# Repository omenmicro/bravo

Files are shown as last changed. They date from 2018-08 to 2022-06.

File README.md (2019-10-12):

# OMEN BRAVO

As-easy-as-possible, but still expandable single board computer with 65C02 CPU.



Become a Patron! (https://www.patreon.com/bePatron?u=23689010)

- [Essential ICs on AliExpress](https://alitronik.com/omen-bravo-pack/)
- [Essential ICs on eBay](https://alitronik.com/omen-bravo-pack-ebay/)

[BOM - Needed parts](./BOM.md)

### Issue 4 is available

Issue 3 adds a 6522 VIA circuit. It features:

- A pair of 8bit parallel ports.
- Each pin of each port can be individually set to the input or to the output.
- Serializer (8 bit shift register)
- A pair of 16bit timer / counter

Issue 4 fixes some problems in the Issue 3 design. See below.

### Issue 3 problem fix

Issue 3 board has some design problems, which is fixed in the Issue 4. Issue 3 is fully working, but you have to manual solder:

- A wire between GND port and a pin 8 of the 74HC138.
- A 180k resistor parallel to the Q1 (between the CPU pins 3 and 37).
- A 47pF capacitor between the CPU pins 1 and 3

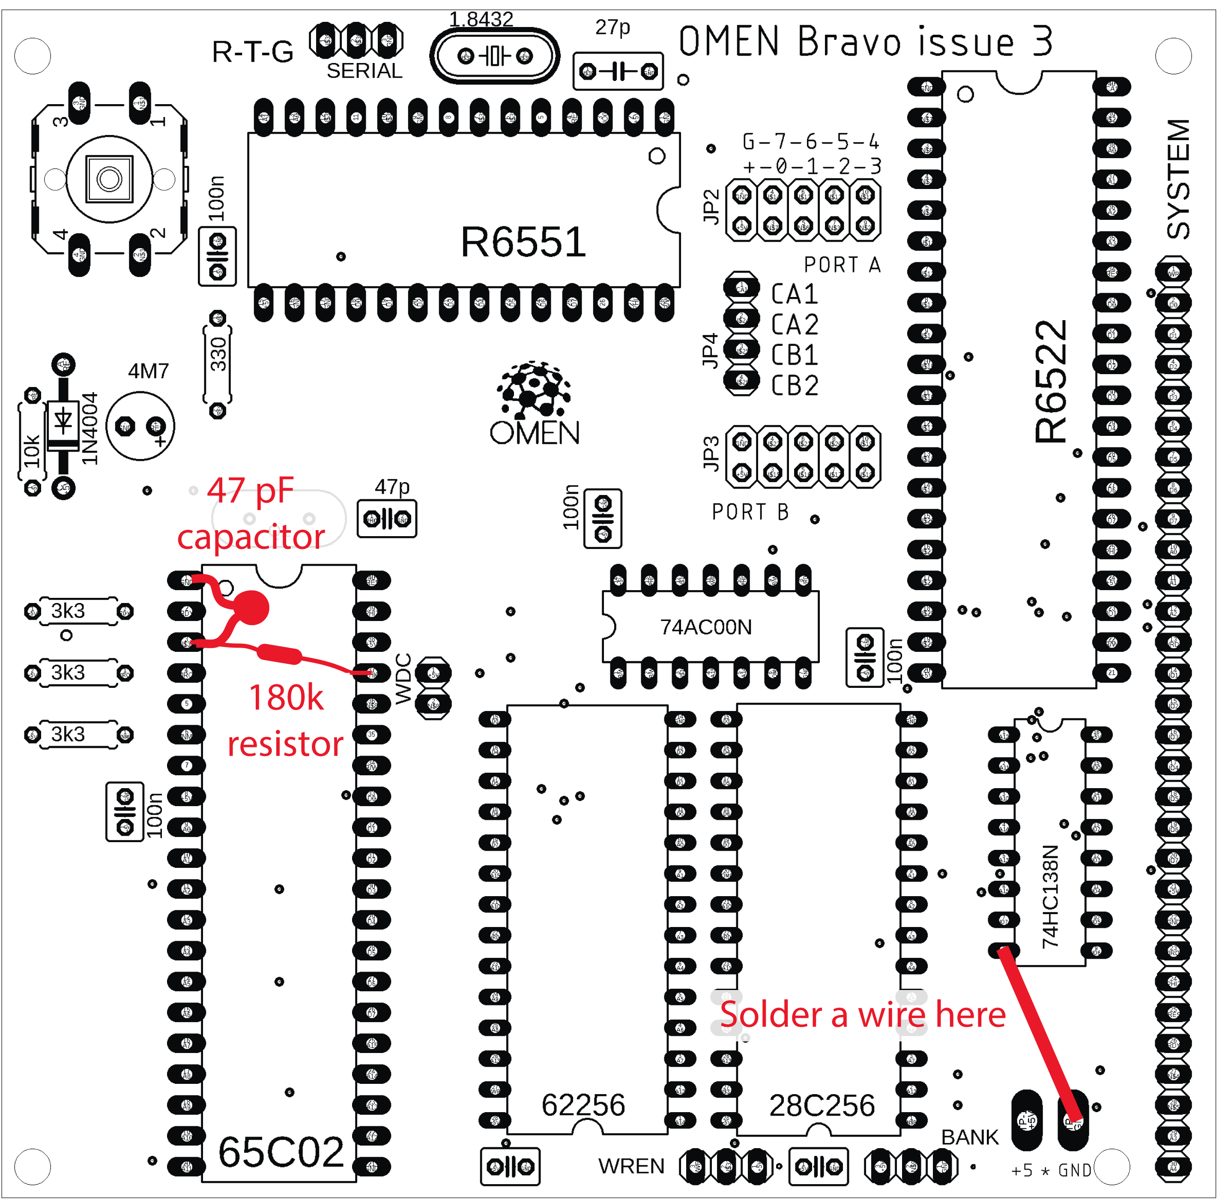
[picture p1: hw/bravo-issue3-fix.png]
Issue 3 fixes


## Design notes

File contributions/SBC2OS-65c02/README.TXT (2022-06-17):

https://sbc.rictor.org/sbcos.html

Here are my SBC-2 Operating System Source Files.

They include:

sbc.asm   - The build file that includes all the other files in the proper order
            (you would assemble this file with TASS)

upload.asm - XMODEM/CRC & Intel-Hex File Upload support
acia.asm - 65c51 init and IO support for monitor
sbcos.asm - monitor & minassembler
reset.asm - reset and IRQ initialization

Compiled using TASS using the following command line:
TASS /c /lsbc.lbl sbc.asm sbc.bin sbcos.lst

The basic idea is to place the upload tables, page aligned, first @ $F700; then let 
all of the code follow sequentially until done.   

The compiler list output file from TASS is called:
sbc25.lst

The label file contains all the labels and their addresses and is called:
sbc.lbl

There is 1 compiled file included:
sbc25.rom  -  the raw binary object file

Current object code occupies $F700-$FFFF

To modify for another target platform, just update the ACIA1.ASM file to 
support these functions:

ACIA1_init - called from reset.asm - initialize the serial terminal device

ACIA1_Input - called from sbc2os.asm - wait for character from terminal, return in Acc

ACIA1_Scan - called from  sbc2os.asm - test for character from terminal - 
             no wait - return with Carry clear for no character, set for character
             last character will be in Acc if carry set - no need to call ACIA1_Input

ACIA1_Output - called from sbc2os.asm - send char in Acc to terminal

In sbc2os.asm, line 40-42, are the calls used from the OS to the terminal.

One note, in the upload.asm file, there are two direct writes to the ACIA1 data register (ACIA1dat).
These are located at lines 363 and 369.  This is in the IntelHex section that ROss Archer contributed.
I'm not sure if a "jsr output" can be substituted or not.

ACIA1dat is defined in the ACIA1.asm file.

This version generates the CRC tables used by xmodem and intel-hex downloaders.  it saves 512 bytes of 
ROM by placing the tables in RAM.  Lines 90 & 91 of upload.asm contain the pointers to the tables.  Put 
these in RAM where they will not be overwritten by the code being downloaded.  They should be page 
aligned for optimal use.

The SBC-2OS command syntax is as follows:

Syntax = {} required, [] optional, HHHH hex address, DD hex data

[HHHH][ HHHH]{Return} - Hex dump address(s)(up to 16 if no address entered)
[HHHH]{.HHHH}{Return} - Hex dump range of addresses (16 per line)
[HHHH]{:DD}[ DD]{Return} - Change data bytes
[HHHH]{G}{Return} - Execute a program (use RTS to return to monitor)
{HHHH.HHHH>HHHH{I}{Return} - move range at 2nd HHHH down to 1st to 3rd HHHH
{HHHH.HHHH>HHHH{M}{Return} - Move range at 1st HHHH thru 2nd to 3rd HHHH
[HHHH][ HHHH]{Q}{Return} - Text dump address(s)
[HHHH]{.HHHH}{Q}{Return} - Text dump range of addresses (16 per line)
{R}{Return} - Print register contents from memory locations - used after BRK if needed
{U}{Return} - Upload File (Xmodem/CRC or Intel Hex)
{V}{Return} - Monitor Version

Good luck!

Daryl

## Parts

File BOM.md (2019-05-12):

[OMEN Bravo](README.md) BOM:

- CPU 65C02 (R65C02 or equivalent type)
- RAM 32kx8 (62256 or equivalent)
- EEPROM 8kx8 (AT28C64 or equivalent, programmed or empty - select the proper variant, or NO EEPROM)
- ACIA (R6551 or equivalent)
- VIA 6522
- Decoder 74138 (HC or HCT)
- Gate 7400 (HC or HCT)
- A printed circuit board
- Crystal 3.6864 MHz (CPU)
- Resonant capacitors 22 pF
- Crystal 1.8432 MHz (for serial communiction)
- Push button
- Diode (1N4004 or similar)
- Resistors (1x 10k, 1x 330R, 1x 180K)
- Electrolytic capacitor 10M
- Filter capacitor (8x 100n)

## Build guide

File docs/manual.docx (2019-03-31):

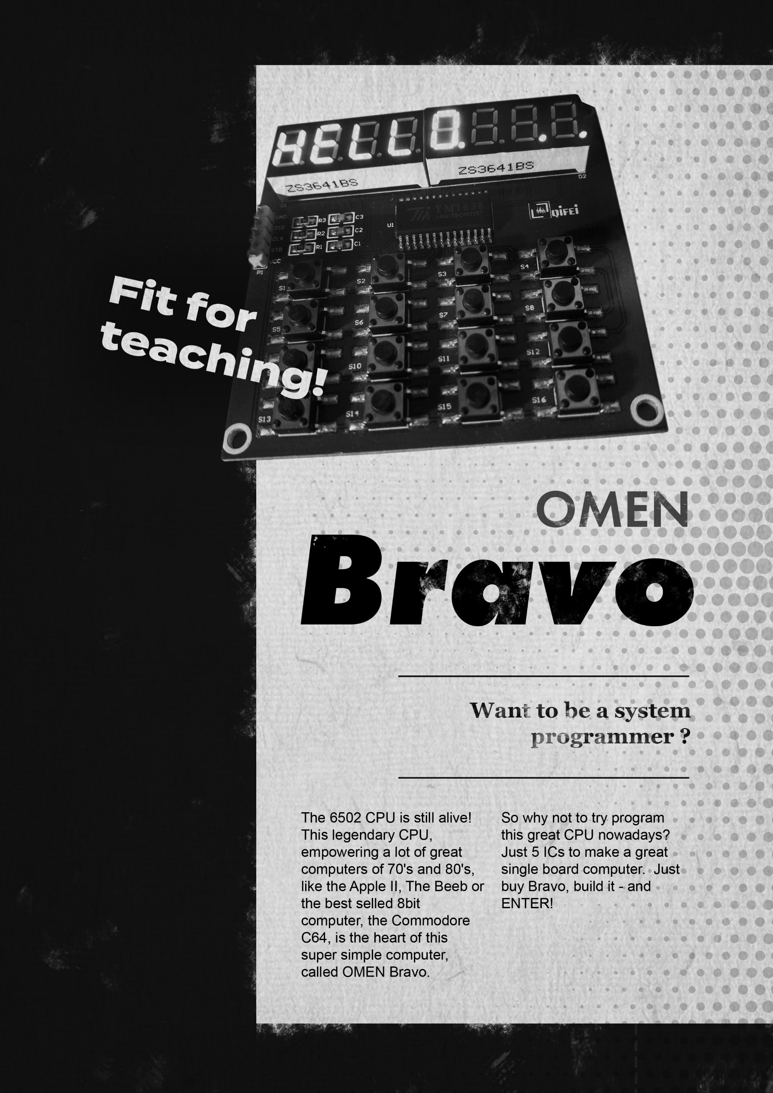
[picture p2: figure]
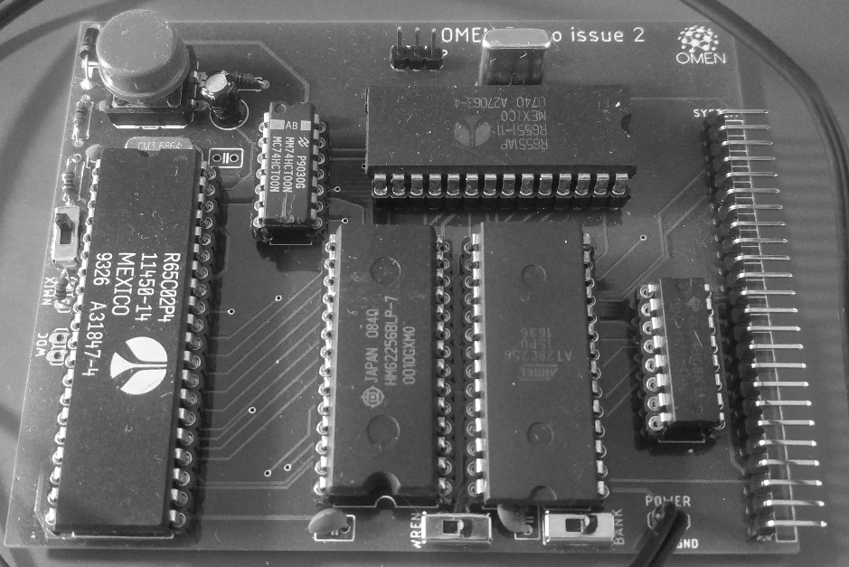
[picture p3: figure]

OMEN Bravo / issue 4

Technical Documentation

INTRODUCTION

===========

The OMEN Bravo computer kit is a low-cost computer trainer, based on the 65C02 CPU. It has these features:

- 65C02 CPU working at 3.6864 MHz
- 32 kB RAM
- 8 kB EEPROM
- Serial port up to 19.200 Bd / MOS 6551 ACIA
- Application system bus

ASSEMBLY INSTRUCTIONS

===================

1. Solder sockets for the integrated circuits
2. Test all soldered connections
  a. Test if all pins are well connected
  b. Check if GND is not short connected to Vcc
  c. Check if each IC has properly connected GND and Vcc
3. Solder all passive parts /capacitors, diode, resistors, push button, crystals/ - pay attention, the Bravo contains two crystals, one for CPU, marked Q1 with value 3.6864, one for serial port, marked “1.8432”
4. Connect the power adapter and check
5. Insert the CPU into its socket /keep the proper orientation!/ and try to power it up. Check if oscillator lives /at CPU pin 39/
6. Insert the essential ICs: 7400, 74138, 62256, 6551 and AT28C64. Again: keep the proper orientation! Bad orientation can damage the IC!
7. Connect the serial pins TxD, RxD and GND /pinhead JP1/ to the TTL-to-USB converter
8. Start the serial terminal on your PC, select proper serial port and set the parameters to 19.200 Bd, 8 data bits, no parity, 1 stop bit.
9. Power your Bravo and check the terminal.

MONITOR

=======

The main software for OMEN Bravo issue 4 is the freeware C’Mon Serial Monitor by Bruce Clark.

You can use the OSI Basic with a minimal effort, as well as the lot of other software.

THE BOARD

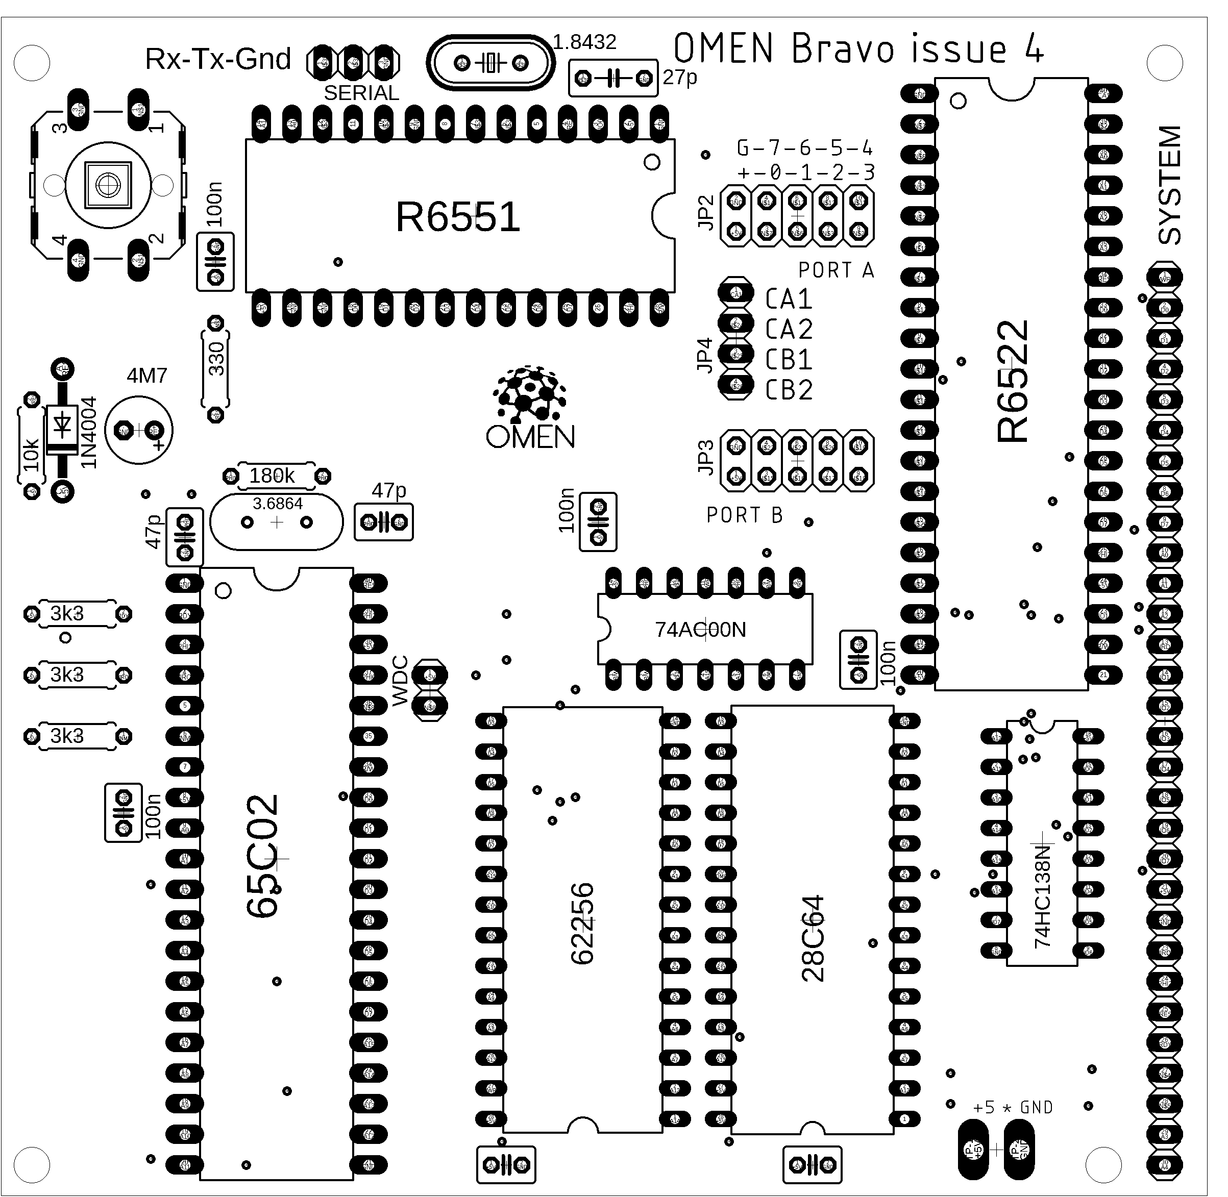
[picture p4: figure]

========

Jumpers and pin headers

SERIAL: Serial port. Pins are RxD, TxD, GND from left to right.

WDC: For Rockwell 65C02 leave open, connect for WDCs W65C02S.

SYSTEM APPLICATION CONNECTOR

=========================

This connector is on the right edge of board. Pin 1 is on the upper side, next to the SYSTEM label.

Pins:

1 /WR
2 D0
3 D1
4 D2
5 D3
6 D4
7 D5
8 D6
9 D7
10 A0
11 A1
12 A2
13 /RD
14 IO1 --- 9000h – 93FFh used for VIA 6522 parallel interface
15 IO2 --- 8800h – 8BFFh
16 IO3 --- 9800h – 9BFFh
17 IO4 --- 8400h – 87FFh IOx signals are decoded by 74138
18 IO5 --- 9400h – 97FFh
19 IO6 --- 8C00h – 8FFFh
20 IO7 --- 9C00h – 9FFFh
21 Vcc
22 GND
23 /IRQ
24 PHI2
25 /RES
26 RDY
27 N/C
28 N/C
29 A3
30 A4

PERIPHERAL IC ADDRESSES
=====================

ACIA 6551:
--------

83FCh – Data Register

83FDh – Status Register

83FEh – Command Register

83FFh - Controll Register

VIA 6522:
-------

93F0h – ORB/IRB
93F1h – ORA/IRA
93F2h – DDRB
93F3h – DDRA
93F4h – T1C-L
93F5h – T1C-H
93F6h – T1L-L
93F7h – T1L-H
93F8h – T2C-L
93F9h – T2C-H
93FAh – SR
93FBh – ACR
93FCh – PCR
93FDh – IFR
93FEh – IER
93FFh – ORA/IRA

MEMORY MAP
==========

0000h – 7FFFh - System RAM 32k

8000h – BFFFh – I/O space, see above

C000h – DFFFh – EEPROM 8k shadow

E000h – FFFFh – EEPROM 8k

C’Mon the Compact Monitor

by Bruce Clark

C'mon, the Compact monitor, is a very small monitor program for the 65C02.

Commands
--------

cr - output a CRLF (and a dash prompt)

0-9A-F - accumulate hex digit

, - store 16-bit "byte" at address, increment address

@ - set address

G - go (call routine)

X - hex/ASCII dump 128 bytes

: - enter the HEX line to store into memory

All other characters are ignored (thus you can use spaces freely). Leading zeros can be omitted. Note that commands execute immediately, i.e. you will get a memory dump when you press X not when you press Enter.

Any routines you call with the G command should return with the D flag clear (they will be called with the D flag clear).

Examples

1234 X - dump 128 bytes starting at address $1234

1234 G - call the routine at address $1234

1234 @ 11,22,33, - store $11, $22 and $33 at address $1234

Single step feature

To single step, use the @ command to set the address, then use the $ (single step) command to single step that instruction. Use $ again to single step the next instruction. After each single step, the program counter (of the next instruction) and the A, S, X, Y, P (in hex), and P (again, but in binary) registers will be output.

If you set the break vector to BREAK, it will save the registers and set the address so that the next instruction (after the signature byte) can be single stepped. Example:

ORG $2000

CLC

LDA #$1234

ADC #$5678

BRK

.byte $0000 ; signature byte (its value is ignored)

EOR #$ABCD

2000G can be used to execute up to the ADC instruction. A subsequent $ command will begin single stepping at the EOR instruction.

Since it isn't always convenient to use BRK, it is also possible to use JSR BRKPT instead of BRK (and its signature byte). Everything about the preceding example would be the same, except that the code would be:

ORG $2000

CLC

LDA #$1234

ADC #$5678

JSR BRKPT

EOR #$ABCD

OMEN Computers - - - https://github.com/osmibity - - - Page: 1

OMEN BRAVO =========

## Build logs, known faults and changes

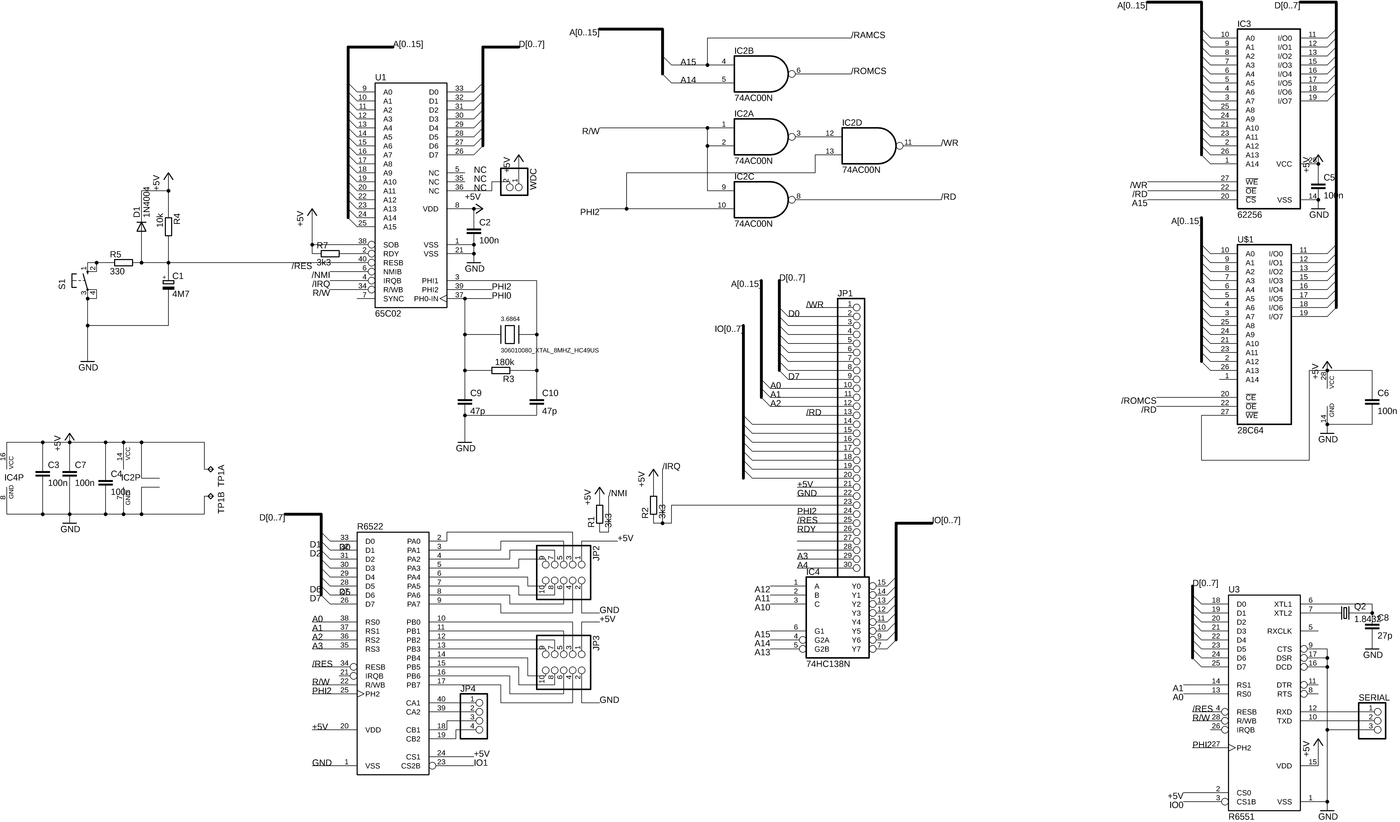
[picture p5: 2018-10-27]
hw/bravo-issue4.png

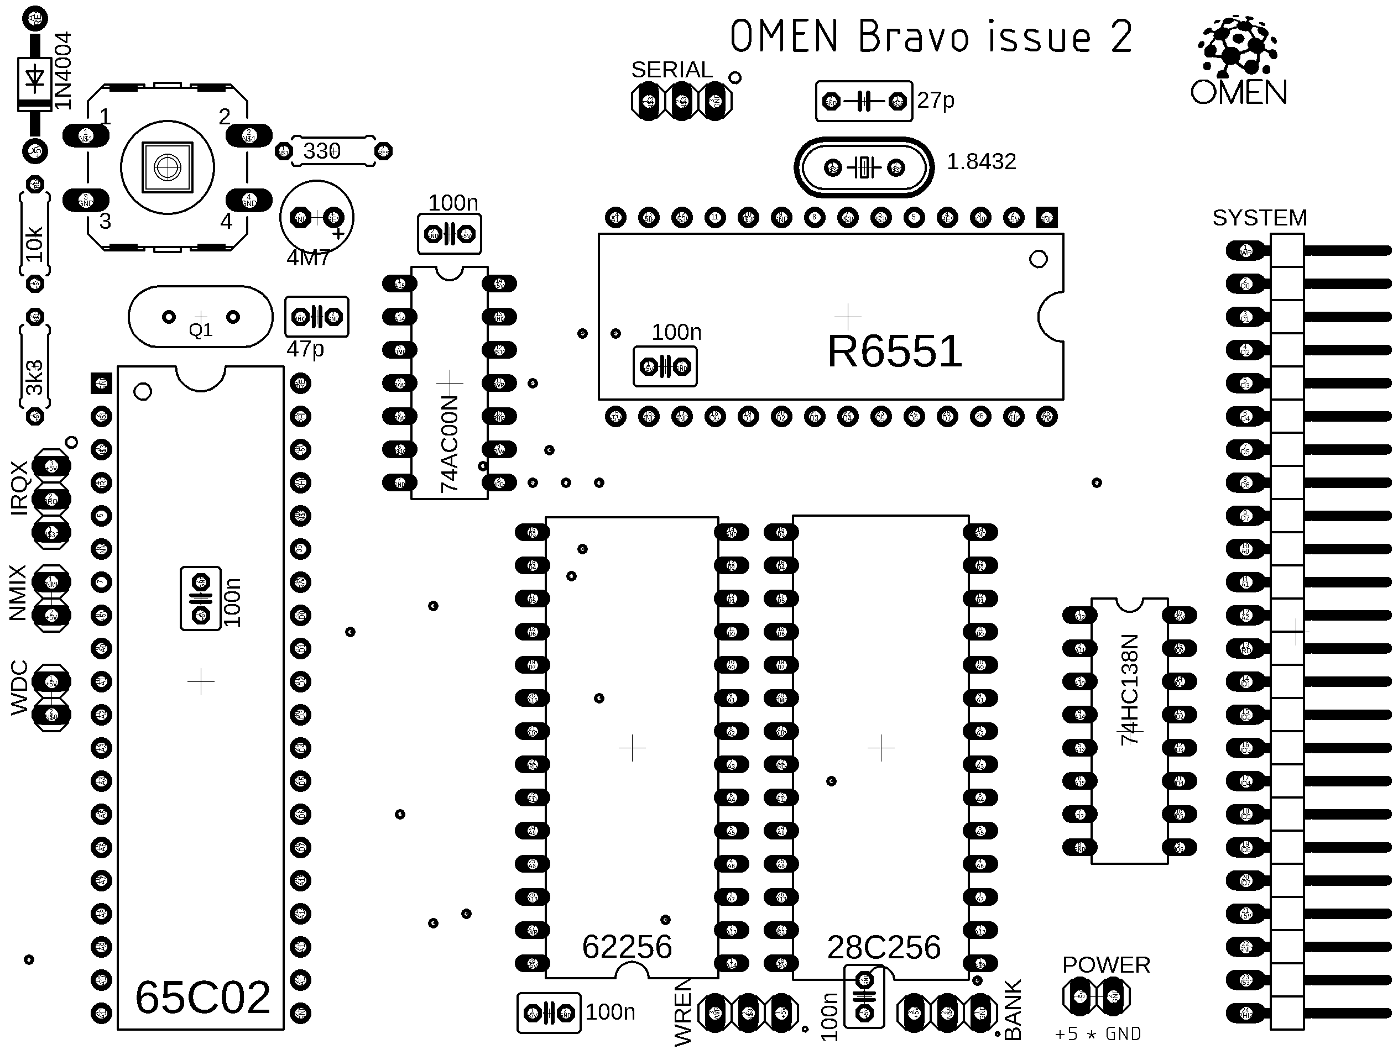
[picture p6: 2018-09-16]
hw/bravo-issue2-board.png

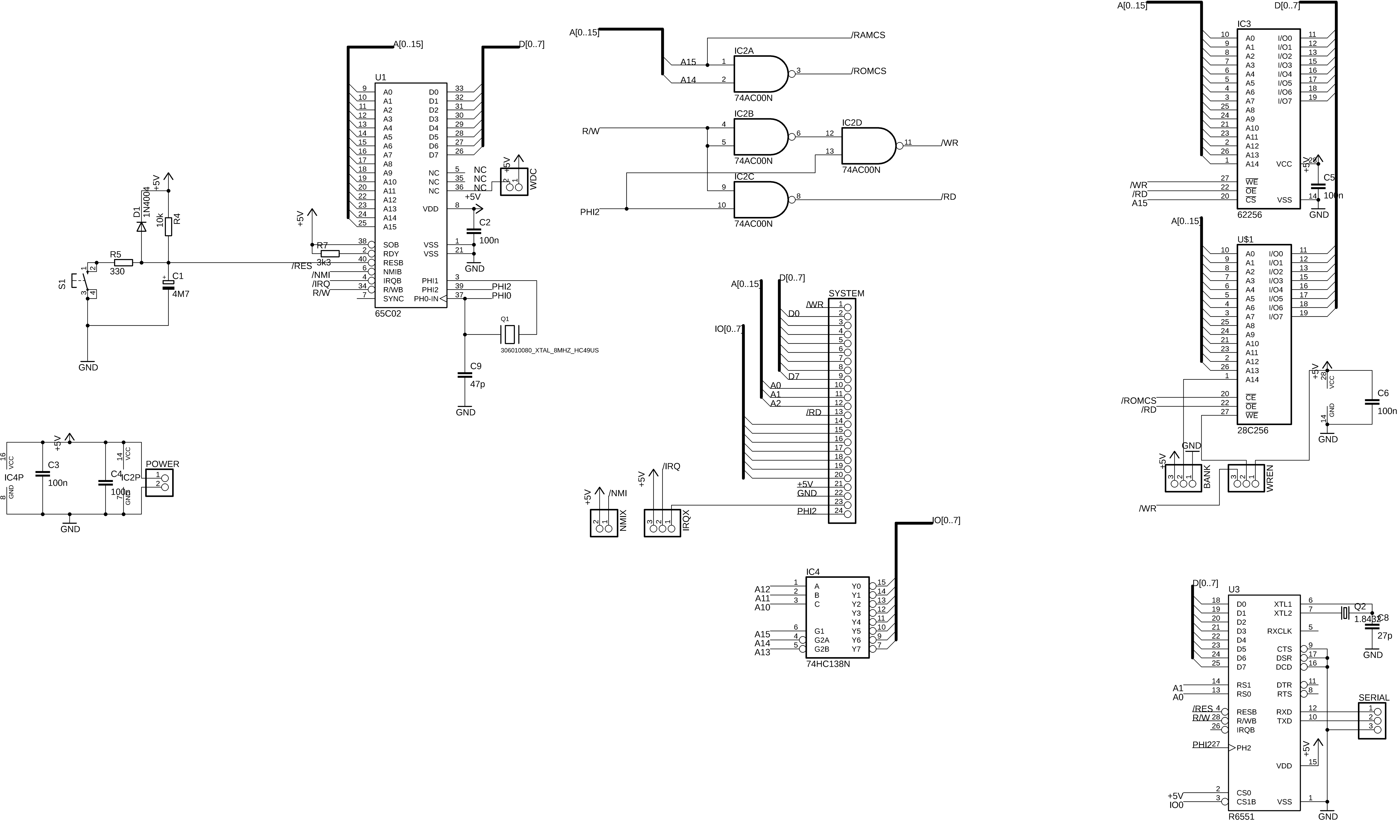
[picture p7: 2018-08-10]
hw/bravo-issue2.png

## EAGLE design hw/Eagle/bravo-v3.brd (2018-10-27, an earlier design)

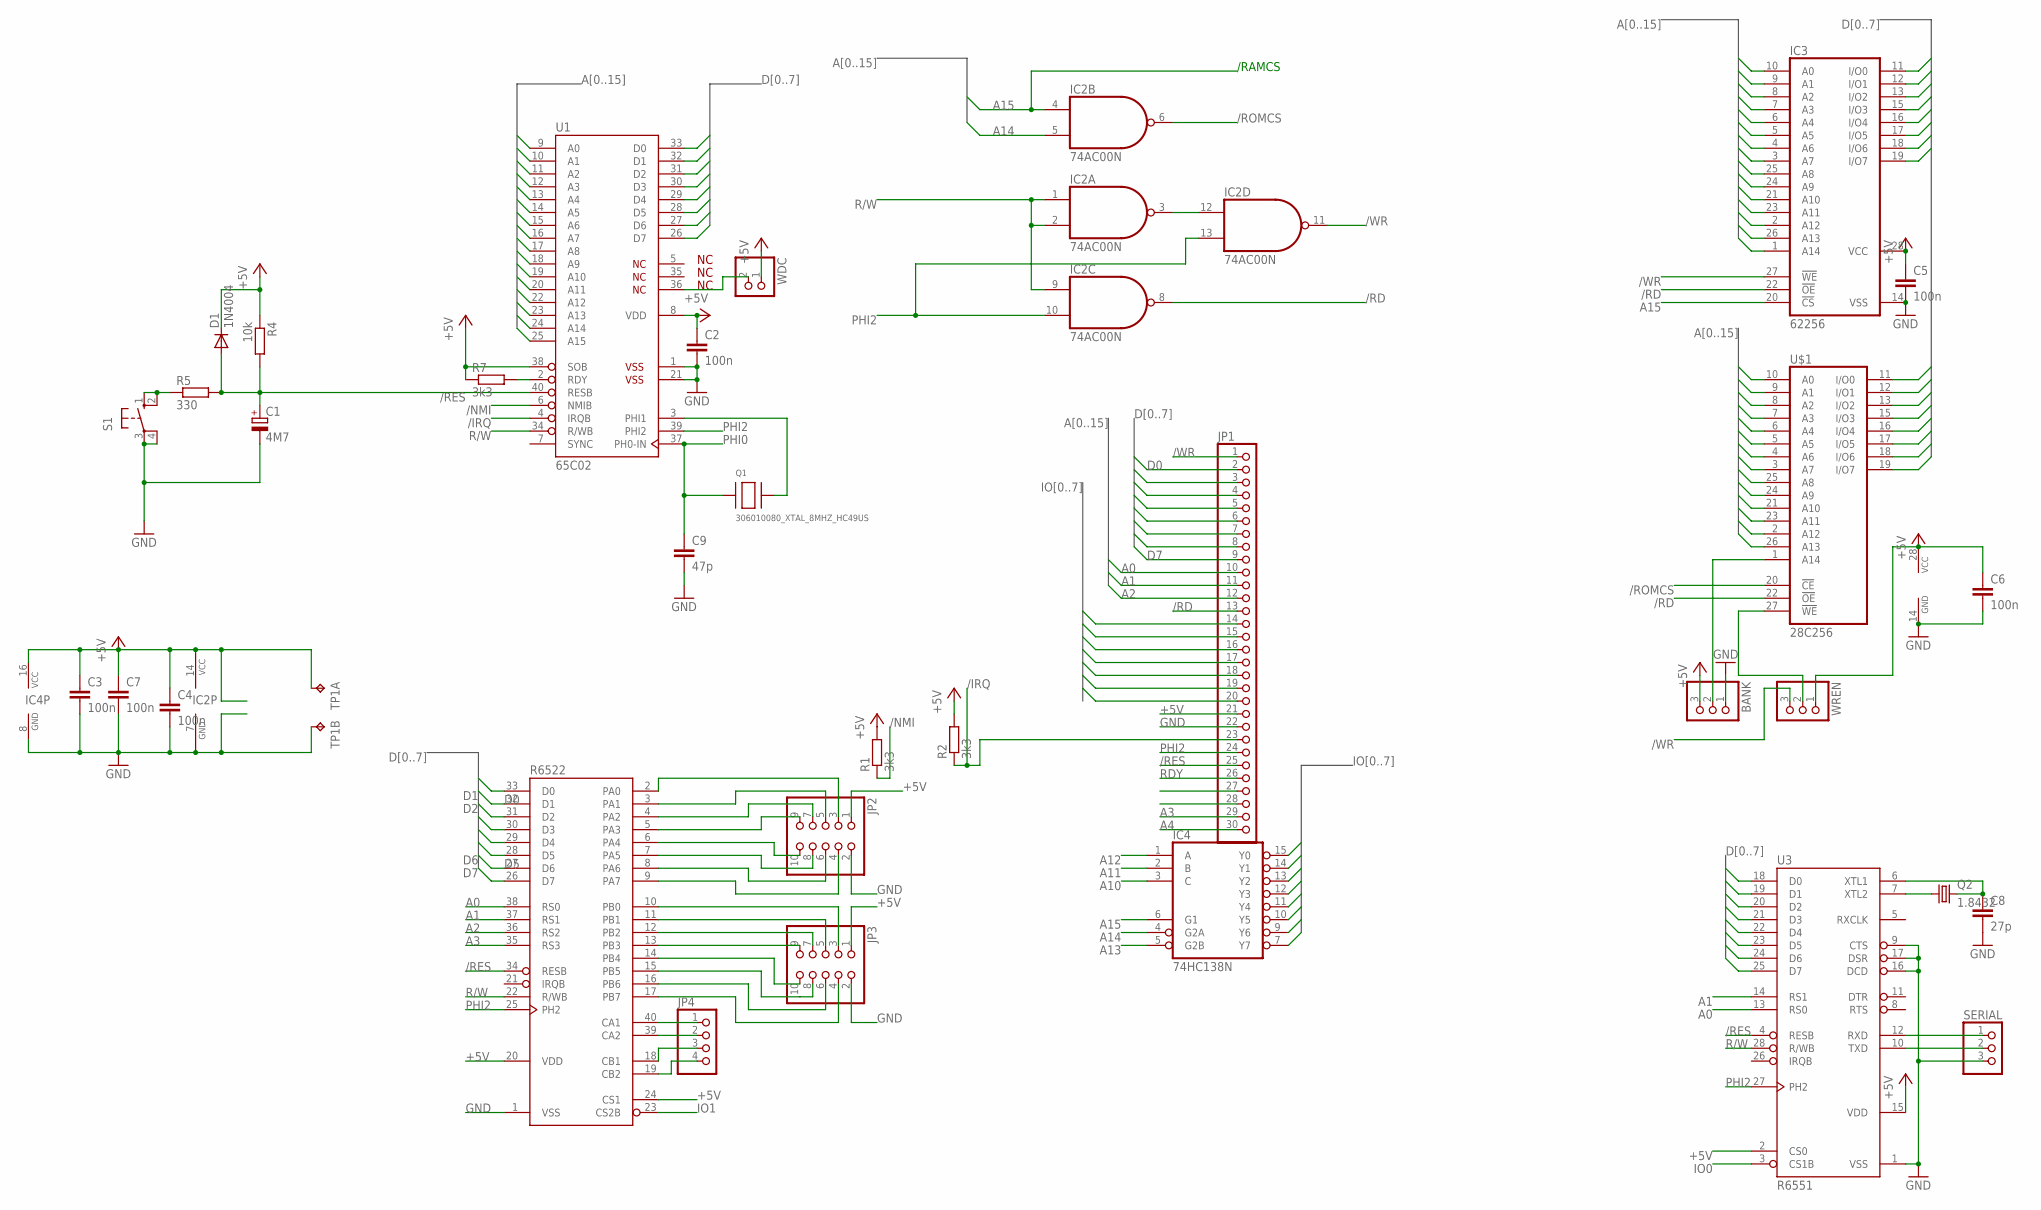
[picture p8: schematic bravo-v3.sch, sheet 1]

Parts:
BANK: PINHD-1X3; 1X03
C1: 4M7; E2,5-6
C2, C3, C4, C5, C6, C7: 100n; C025-030X050
C8: 27p; C050-030X075
C9: 47p; C025-030X050
D1: 1N4004; DO41-10
IC2: 74AC00N; DIL14
IC3: 62256; DIL28-6
IC4: 74HC138N; DIL16
JP1: PINHD-1X30; 1X30
JP2, JP3: PINHD-2X5; 2X05
JP4: PINHD-1X4; 1X04
Q1: 306010080_XTAL_8MHZ_HC49US; HC49US
Q2: 1.8432; HC49/S
R1, R2, R7: 3k3; 0207/7
R4: 10k; 0207/7
R5: 330; 0207/7
R6522: G65SC22P; DIP-40
S1: 40-XX; B3F-40XX
SERIAL: PINHD-1X3; 1X03
TP1: TP2P2-38-17; P2-38-17
U1: 65C02; DIP-40
U3: R6551; DIP-28
U$1: 28C256; DIL28
WDC: PINHD-1X2; 1X02
WREN: PINHD-1X3; 1X03

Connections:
+5V: BANK.3, C2.1, C3.1, C4.1, C5.1, C6.1, C7.1, D1.C, IC2.14 (VCC), IC3.28 (VCC), IC4.16 (VCC), JP1.21, JP2.1, JP3.1, R1.2, R2.2, R4.1, R7.1, R6522.20 (VDD), R6522.24 (CS1), TP1.TP-1, U1.8 (VDD), U1.38 (SOB), U3.2 (CS0), U3.15 (VDD), U$1.28 (VCC), WDC.1, WREN.1
/IRQ: JP1.23, R2.1, U1.4 (IRQB)
/NMI: R1.1, U1.6 (NMIB)
/RD: IC2.8 (O), IC3.22 (!OE), JP1.13, U$1.22 (!OE)
/RES: C1.+, D1.A, JP1.25, R4.2, R5.2, R6522.34 (RESB), U1.40 (RESB), U3.4 (RESB)
/ROMCS: IC2.6 (O), U$1.20 (!CE)
/WR: IC2.11 (O), IC3.27 (!WE), JP1.1, WREN.3
A0: IC3.10 (A0), JP1.10, R6522.38 (RS0), U1.9 (A0), U3.13 (RS0), U$1.10 (A0)
A1: IC3.9 (A1), JP1.11, R6522.37 (RS1), U1.10 (A1), U3.14 (RS1), U$1.9 (A1)
A2: IC3.8 (A2), JP1.12, R6522.36 (RS2), U1.11 (A2), U$1.8 (A2)
A3: IC3.7 (A3), JP1.29, R6522.35 (RS3), U1.12 (A3), U$1.7 (A3)
A4: IC3.6 (A4), JP1.30, U1.13 (A4), U$1.6 (A4)
A5: IC3.5 (A5), U1.14 (A5), U$1.5 (A5)
A6: IC3.4 (A6), U1.15 (A6), U$1.4 (A6)
A7: IC3.3 (A7), U1.16 (A7), U$1.3 (A7)
A8: IC3.25 (A8), U1.17 (A8), U$1.25 (A8)
A9: IC3.24 (A9), U1.18 (A9), U$1.24 (A9)
A10: IC3.21 (A10), IC4.3 (C), U1.19 (A10), U$1.21 (A10)
A11: IC3.23 (A11), IC4.2 (B), U1.20 (A11), U$1.23 (A11)
A12: IC3.2 (A12), IC4.1 (A), U1.22 (A12), U$1.2 (A12)
A13: IC3.26 (A13), IC4.5 (G2B), U1.23 (A13), U$1.26 (A13)
A14: IC2.5 (I1), IC3.1 (A14), IC4.4 (G2A), U1.24 (A14)
A15: IC2.4 (I0), IC3.20 (!CS), IC4.6 (G1), U1.25 (A15)
CA1: JP4.1, R6522.40 (CA1)
D0: IC3.11 (I/O0), JP1.2, R6522.33 (D0), U1.33 (D0), U3.18 (D0), U$1.11 (I/O0)
D1: IC3.12 (I/O1), JP1.3, R6522.32 (D1), U1.32 (D1), U3.19 (D1), U$1.12 (I/O1)
D2: IC3.13 (I/O2), JP1.4, R6522.31 (D2), U1.31 (D2), U3.20 (D2), U$1.13 (I/O2)
D3: IC3.15 (I/O3), JP1.5, R6522.30 (D3), U1.30 (D3), U3.21 (D3), U$1.15 (I/O3)
D4: IC3.16 (I/O4), JP1.6, R6522.29 (D4), U1.29 (D4), U3.22 (D4), U$1.16 (I/O4)
D5: IC3.17 (I/O5), JP1.7, R6522.28 (D5), U1.28 (D5), U3.23 (D5), U$1.17 (I/O5)
D6: IC3.18 (I/O6), JP1.8, R6522.27 (D6), U1.27 (D6), U3.24 (D6), U$1.18 (I/O6)
D7: IC3.19 (I/O7), JP1.9, R6522.26 (D7), U1.26 (D7), U3.25 (D7), U$1.19 (I/O7)
GND: BANK.1, C1.-, C2.2, C3.2, C4.2, C5.2, C6.2, C7.2, C8.2, C9.2, IC2.7 (GND), IC3.14 (VSS), IC4.8 (GND), JP1.22, JP2.2, JP3.2, R6522.1 (VSS), S1.3, S1.4 (P1), SERIAL.3, TP1.TP-2, U1.1 (VSS$1), U1.21 (VSS$2), U3.1 (VSS), U3.9 (CTS), U3.16 (DCD), U3.17 (DSR), U$1.14 (GND)
IO0: IC4.15 (Y0), U3.3 (CS1B)
IO1: IC4.14 (Y1), JP1.14, R6522.23 (CS2B)
IO2: IC4.13 (Y2), JP1.15
IO3: IC4.12 (Y3), JP1.16
IO4: IC4.11 (Y4), JP1.17
IO5: IC4.10 (Y5), JP1.18
IO6: IC4.9 (Y6), JP1.19
IO7: IC4.7 (Y7), JP1.20
unnamed: R5.1, S1.1 (S), S1.2 (S1)
unnamed: JP2.9, R6522.5 (PA3)
unnamed: JP2.7, R6522.4 (PA2)
unnamed: JP2.5, R6522.3 (PA1)
unnamed: JP2.3, R6522.2 (PA0)
unnamed: U1.36 (NC$3), WDC.2
unnamed: BANK.2, U$1.1 (A14)
unnamed: IC2.3 (O), IC2.12 (I0)
unnamed: JP2.10, R6522.6 (PA4)
unnamed: JP2.8, R6522.7 (PA5)
unnamed: JP2.6, R6522.8 (PA6)
unnamed: JP2.4, R6522.9 (PA7)
unnamed: JP3.3, R6522.10 (PB0)
unnamed: JP3.5, R6522.11 (PB1)
unnamed: JP3.7, R6522.12 (PB2)
unnamed: JP3.9, R6522.13 (PB3)
unnamed: JP3.10, R6522.14 (PB4)
unnamed: JP3.8, R6522.15 (PB5)
unnamed: JP3.6, R6522.16 (PB6)
unnamed: JP3.4, R6522.17 (PB7)
unnamed: JP4.2, R6522.39 (CA2)
unnamed: JP4.3, R6522.18 (CB1)
unnamed: JP4.4, R6522.19 (CB2)
unnamed: U$1.27 (!WE), WREN.2
unnamed: Q1.P$2, U1.3 (PHI1)
unnamed: SERIAL.1, U3.12 (RXD)
unnamed: SERIAL.2, U3.10 (TXD)
unnamed: Q2.1, U3.7 (XTL2)
unnamed: C8.1, Q2.2, U3.6 (XTL1)
PHI0: C9.1, Q1.P$1, U1.37 (PH0-IN)
PHI2: IC2.10 (I1), IC2.13 (I1), JP1.24, R6522.25 (PH2), U1.39 (PHI2), U3.27 (PH2)
R/W: IC2.1 (I0), IC2.2 (I1), IC2.9 (I0), R6522.22 (R/WB), U1.34 (R/WB), U3.28 (R/WB)
RDY: JP1.26, R7.2, U1.2 (RDY)

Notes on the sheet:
/RAMCS

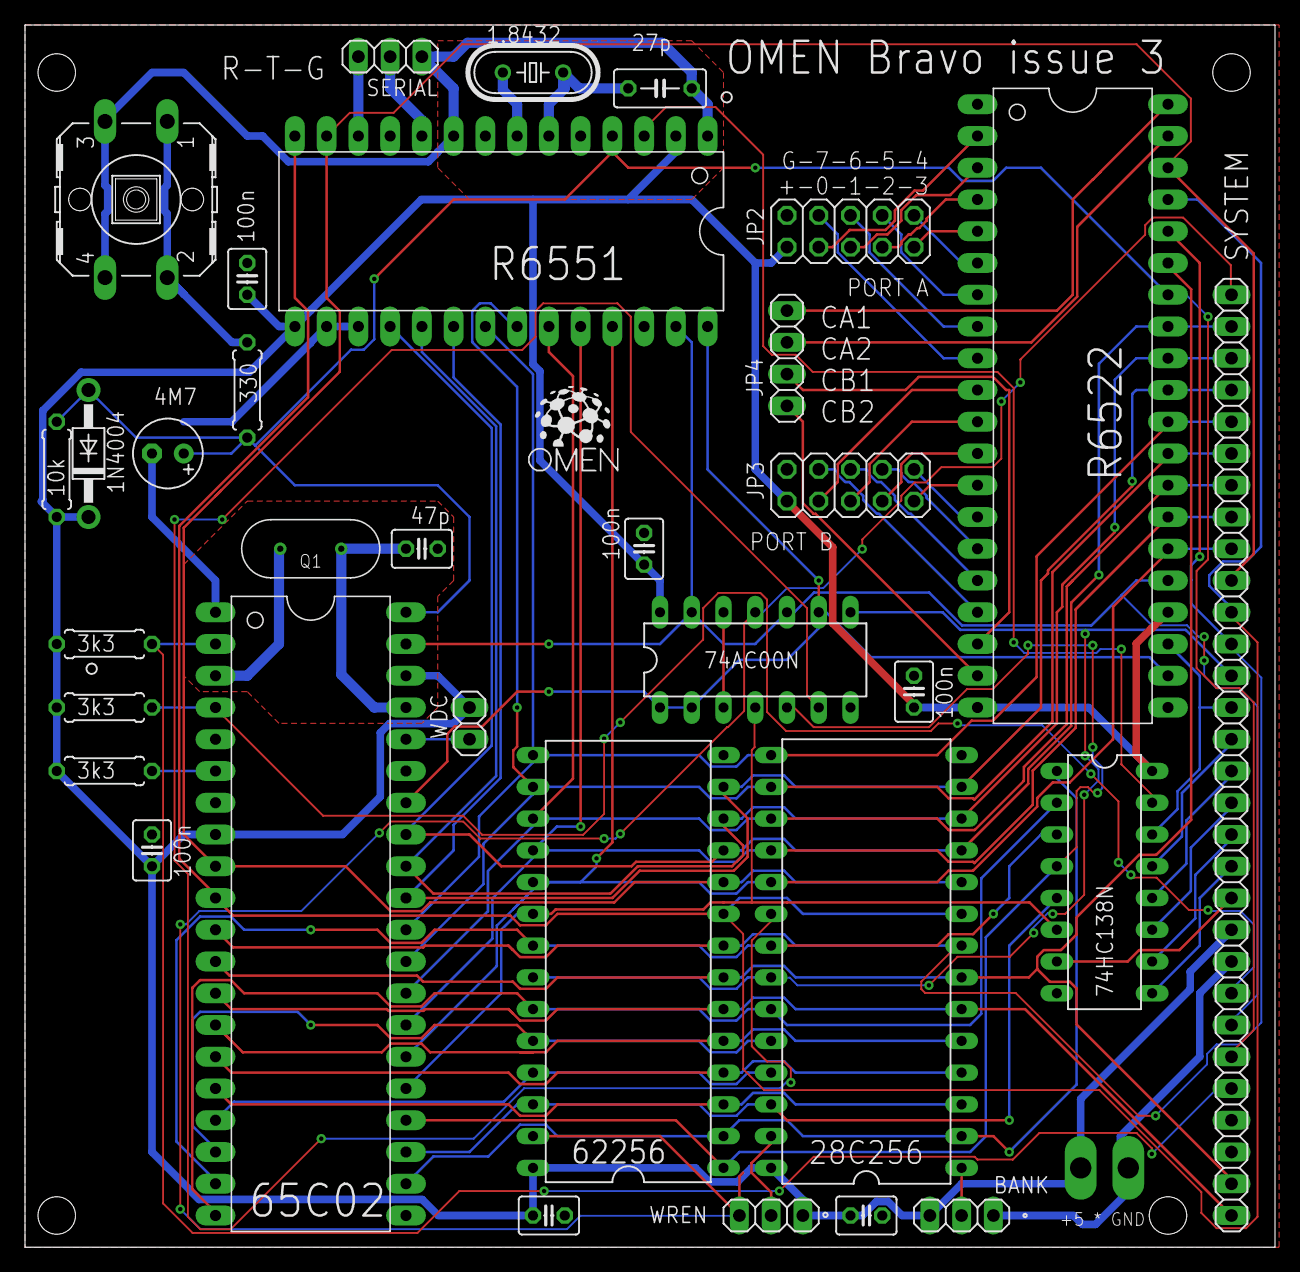
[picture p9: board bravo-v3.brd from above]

Board: 2 copper layers, 100.0 x 97.8 mm, 34 parts (0 on the bottom side), 74 nets.

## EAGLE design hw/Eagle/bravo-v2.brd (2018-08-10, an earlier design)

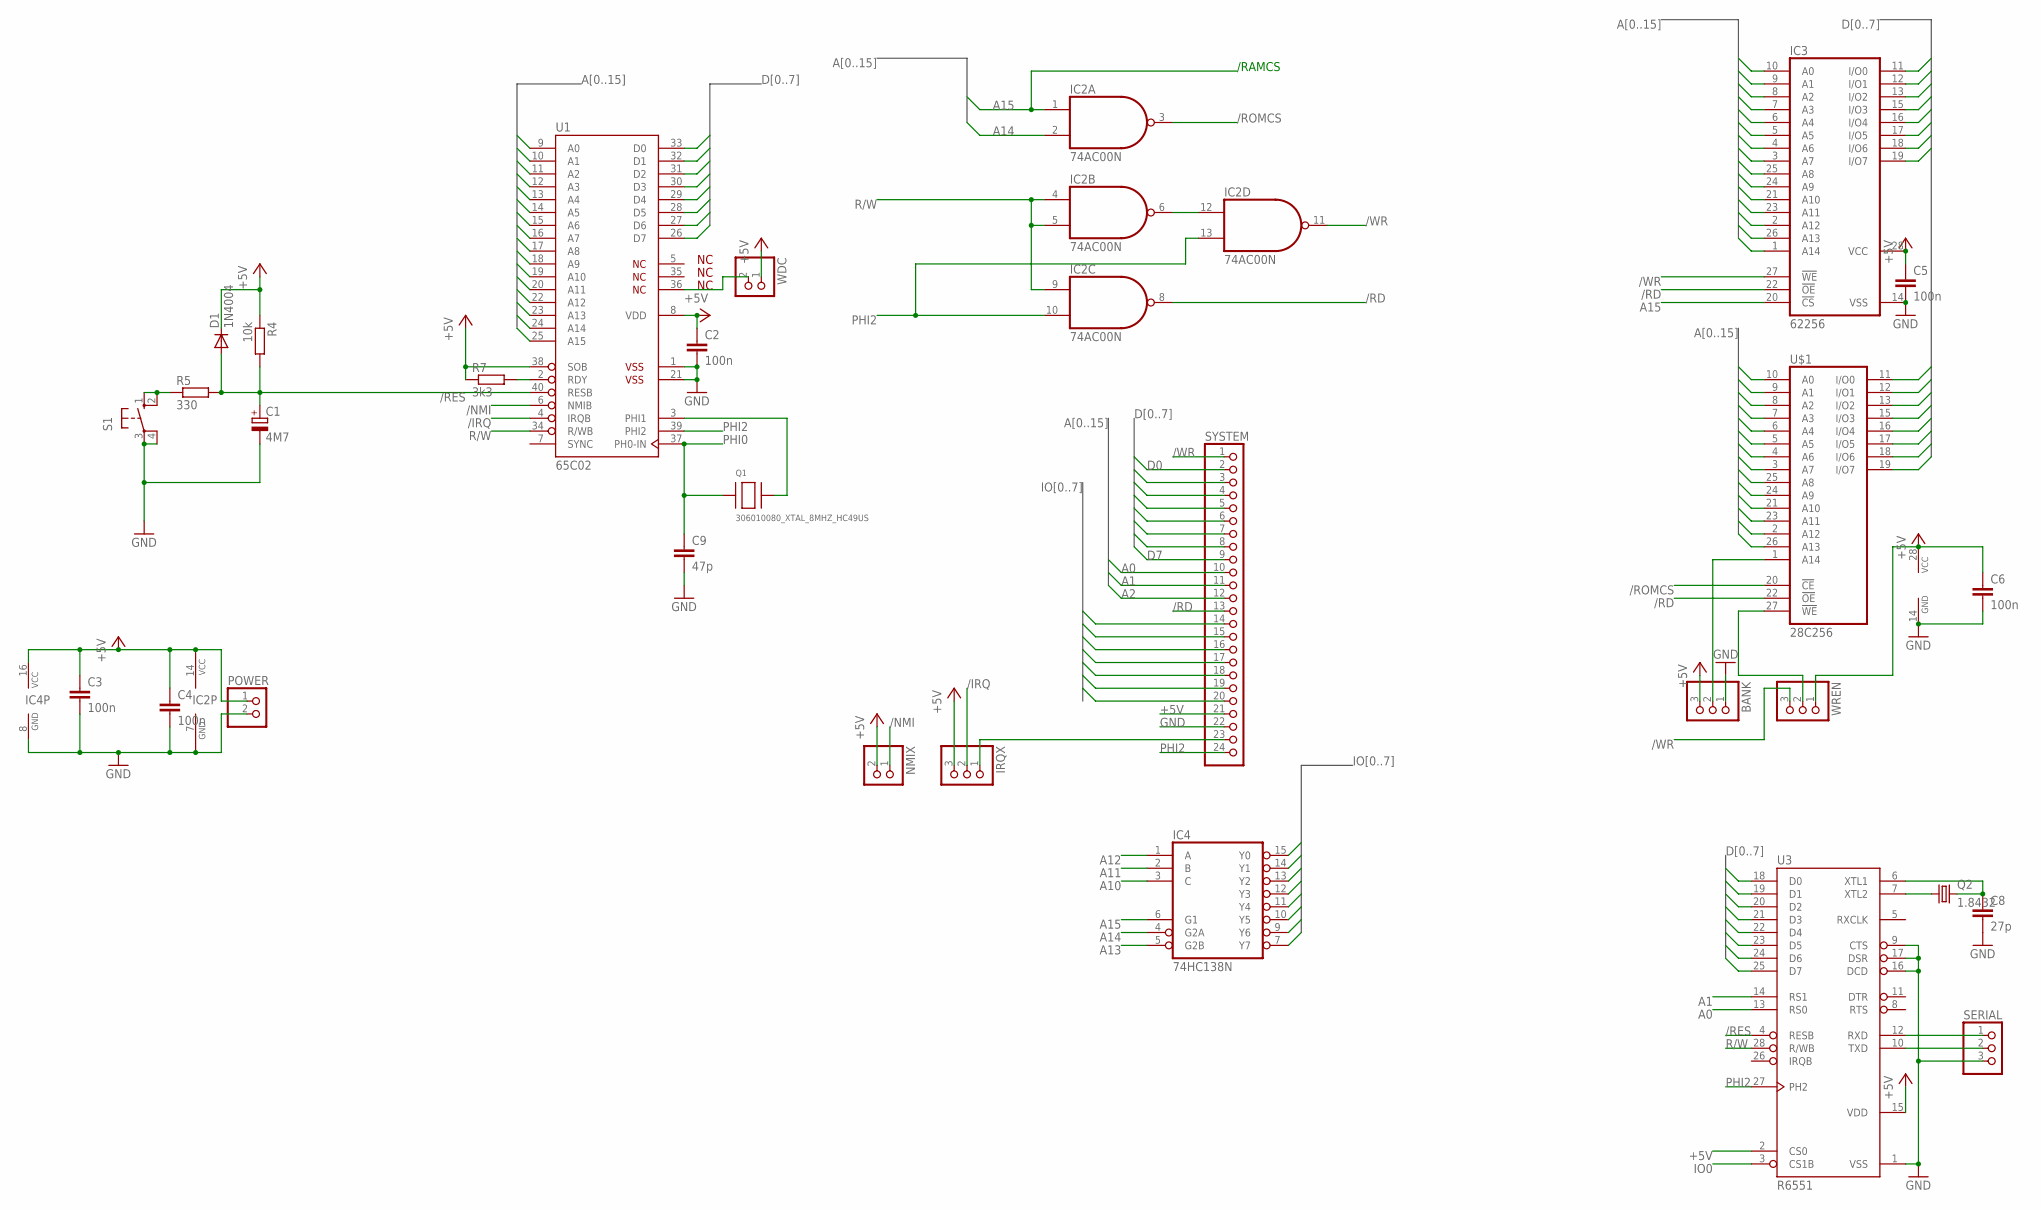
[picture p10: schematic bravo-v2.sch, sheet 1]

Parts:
BANK: PINHD-1X3; 1X03
C1: 4M7; E2,5-6
C2, C3, C4, C5, C6: 100n; C025-030X050
C8: 27p; C050-030X075
C9: 47p; C025-030X050
D1: 1N4004; DO41-10
IC2: 74AC00N; DIL14
IC3: 62256; DIL28-6
IC4: 74HC138N; DIL16
IRQX: PINHD-1X3; 1X03
NMIX: PINHD-1X2; 1X02
POWER: PINHD-1X2; 1X02
Q1: 306010080_XTAL_8MHZ_HC49US; HC49US
Q2: 1.8432; HC49/S
R4: 10k; 0207/7
R5: 330; 0207/7
R7: 3k3; 0207/7
S1: 40-XX; B3F-40XX
SERIAL: PINHD-1X3; 1X03
SYSTEM: PINHD-1X24/90; 1X24/90
U1: 65C02; DIP-40
U3: R6551; DIP-28
U$1: 28C256; DIL28
WDC: PINHD-1X2; 1X02
WREN: PINHD-1X3; 1X03

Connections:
+5V: BANK.3, C2.1, C3.1, C4.1, C5.1, C6.1, D1.C, IC2.14 (VCC), IC3.28 (VCC), IC4.16 (VCC), IRQX.3, NMIX.2, POWER.1, R4.1, R7.1, SYSTEM.21, U1.8 (VDD), U1.38 (SOB), U3.2 (CS0), U3.15 (VDD), U$1.28 (VCC), WDC.1, WREN.1
/IRQ: IRQX.2, U1.4 (IRQB)
/NMI: NMIX.1, U1.6 (NMIB)
/RD: IC2.8 (O), IC3.22 (!OE), SYSTEM.13, U$1.22 (!OE)
/RES: C1.+, D1.A, R4.2, R5.2, U1.40 (RESB), U3.4 (RESB)
/ROMCS: IC2.3 (O), U$1.20 (!CE)
/WR: IC2.11 (O), IC3.27 (!WE), SYSTEM.1, WREN.3
A0: IC3.10 (A0), SYSTEM.10, U1.9 (A0), U3.13 (RS0), U$1.10 (A0)
A1: IC3.9 (A1), SYSTEM.11, U1.10 (A1), U3.14 (RS1), U$1.9 (A1)
A2: IC3.8 (A2), SYSTEM.12, U1.11 (A2), U$1.8 (A2)
A3: IC3.7 (A3), U1.12 (A3), U$1.7 (A3)
A4: IC3.6 (A4), U1.13 (A4), U$1.6 (A4)
A5: IC3.5 (A5), U1.14 (A5), U$1.5 (A5)
A6: IC3.4 (A6), U1.15 (A6), U$1.4 (A6)
A7: IC3.3 (A7), U1.16 (A7), U$1.3 (A7)
A8: IC3.25 (A8), U1.17 (A8), U$1.25 (A8)
A9: IC3.24 (A9), U1.18 (A9), U$1.24 (A9)
A10: IC3.21 (A10), IC4.3 (C), U1.19 (A10), U$1.21 (A10)
A11: IC3.23 (A11), IC4.2 (B), U1.20 (A11), U$1.23 (A11)
A12: IC3.2 (A12), IC4.1 (A), U1.22 (A12), U$1.2 (A12)
A13: IC3.26 (A13), IC4.5 (G2B), U1.23 (A13), U$1.26 (A13)
A14: IC2.2 (I1), IC3.1 (A14), IC4.4 (G2A), U1.24 (A14)
A15: IC2.1 (I0), IC3.20 (!CS), IC4.6 (G1), U1.25 (A15)
D0: IC3.11 (I/O0), SYSTEM.2, U1.33 (D0), U3.18 (D0), U$1.11 (I/O0)
D1: IC3.12 (I/O1), SYSTEM.3, U1.32 (D1), U3.19 (D1), U$1.12 (I/O1)
D2: IC3.13 (I/O2), SYSTEM.4, U1.31 (D2), U3.20 (D2), U$1.13 (I/O2)
D3: IC3.15 (I/O3), SYSTEM.5, U1.30 (D3), U3.21 (D3), U$1.15 (I/O3)
D4: IC3.16 (I/O4), SYSTEM.6, U1.29 (D4), U3.22 (D4), U$1.16 (I/O4)
D5: IC3.17 (I/O5), SYSTEM.7, U1.28 (D5), U3.23 (D5), U$1.17 (I/O5)
D6: IC3.18 (I/O6), SYSTEM.8, U1.27 (D6), U3.24 (D6), U$1.18 (I/O6)
D7: IC3.19 (I/O7), SYSTEM.9, U1.26 (D7), U3.25 (D7), U$1.19 (I/O7)
GND: BANK.1, C1.-, C2.2, C3.2, C4.2, C5.2, C6.2, C8.2, C9.2, IC2.7 (GND), IC3.14 (VSS), IC4.8 (GND), POWER.2, S1.3, S1.4 (P1), SERIAL.3, SYSTEM.22, U1.1 (VSS$1), U1.21 (VSS$2), U3.1 (VSS), U3.9 (CTS), U3.16 (DCD), U3.17 (DSR), U$1.14 (GND)
IO0: IC4.15 (Y0), U3.3 (CS1B)
IO1: IC4.14 (Y1), SYSTEM.14
IO2: IC4.13 (Y2), SYSTEM.15
IO3: IC4.12 (Y3), SYSTEM.16
IO4: IC4.11 (Y4), SYSTEM.17
IO5: IC4.10 (Y5), SYSTEM.18
IO6: IC4.9 (Y6), SYSTEM.19
IO7: IC4.7 (Y7), SYSTEM.20
unnamed: R5.1, S1.1 (S), S1.2 (S1)
unnamed: U1.36 (NC$3), WDC.2
unnamed: BANK.2, U$1.1 (A14)
unnamed: IC2.6 (O), IC2.12 (I0)
unnamed: R7.2, U1.2 (RDY)
unnamed: U$1.27 (!WE), WREN.2
unnamed: IRQX.1, SYSTEM.23
unnamed: Q1.P$2, U1.3 (PHI1)
unnamed: SERIAL.1, U3.12 (RXD)
unnamed: SERIAL.2, U3.10 (TXD)
unnamed: Q2.1, U3.7 (XTL2)
unnamed: C8.1, Q2.2, U3.6 (XTL1)
PHI0: C9.1, Q1.P$1, U1.37 (PH0-IN)
PHI2: IC2.10 (I1), IC2.13 (I1), SYSTEM.24, U1.39 (PHI2), U3.27 (PH2)
R/W: IC2.4 (I0), IC2.5 (I1), IC2.9 (I0), U1.34 (R/WB), U3.28 (R/WB)

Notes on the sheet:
/RAMCS

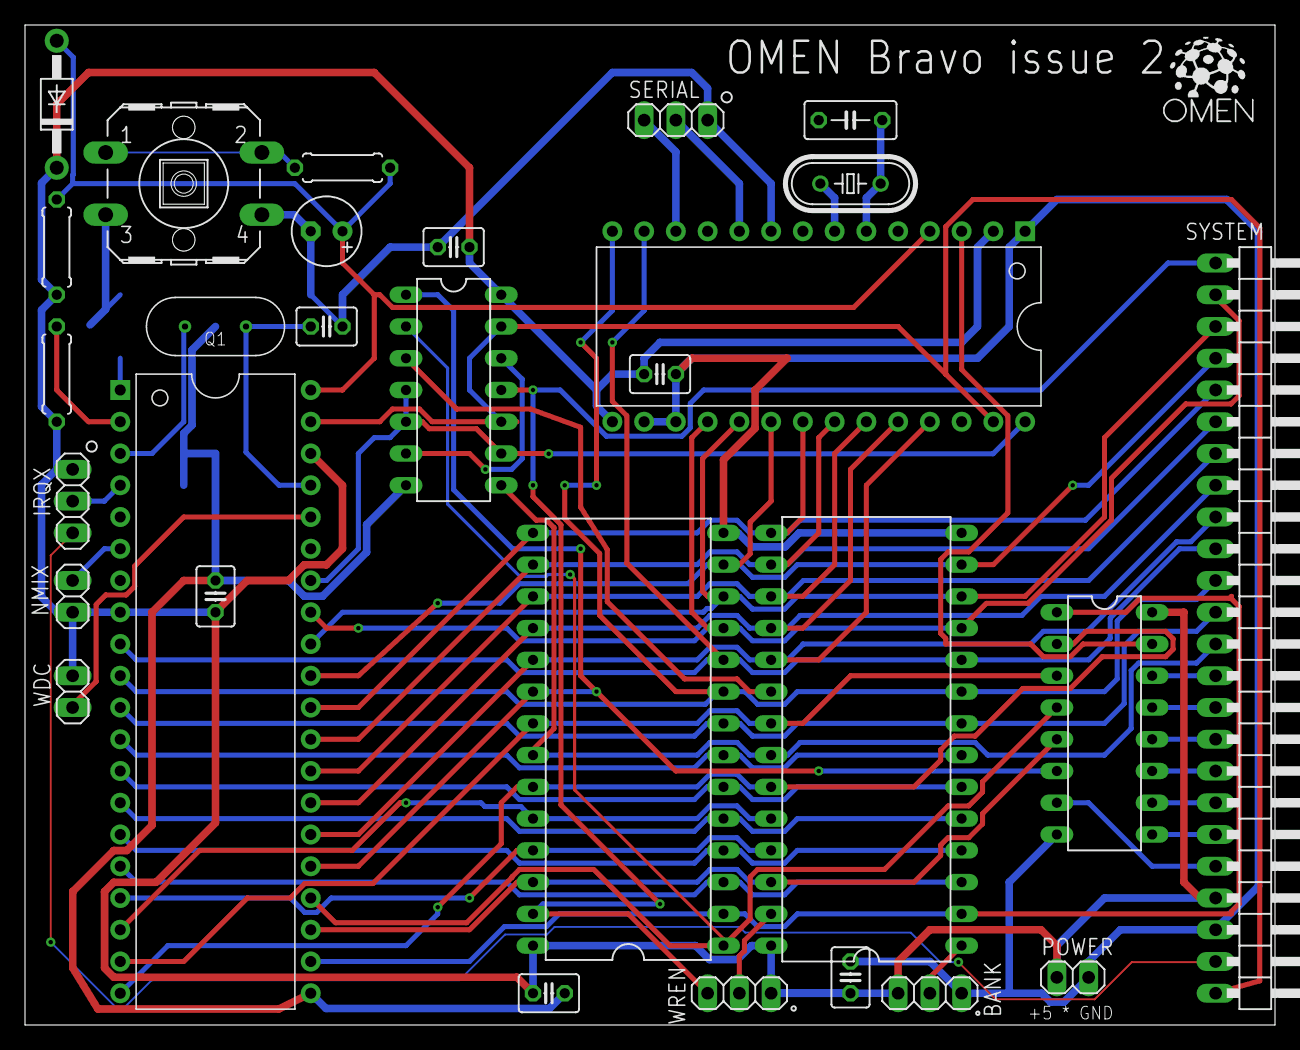
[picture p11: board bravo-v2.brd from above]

Board: 2 copper layers, 100.0 x 80.0 mm, 29 parts (0 on the bottom side), 55 nets.

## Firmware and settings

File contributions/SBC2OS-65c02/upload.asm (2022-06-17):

; upload.asm   (hooked into SbcOS at $fa00-feff)
; By Daryl Rictor & Ross Archer  Aug 2002
;
; 21st century code for 20th century CPUs (tm?)
; 
; A simple file transfer program to allow upload from a serial
; port to the SBC.  It integrates both x-modem/CRC transfer protocol 
; and Intel Hex formatted files. Primary is XMODEM-CRC, due to its
; superior reliability.  Fallback to Intel Hex is automagical following
; receipt of the first Hexfile d/l character, so the selection is 
; transparent to the user.
;
; Files uploaded via XMODEM-CRC must be
; in .o64 format -- the first two bytes are the load address in
; little-endian format:  
;  FIRST BLOCK
;     offset(0) = lo(load start address),
;     offset(1) = hi(load start address)
;     offset(2) = data byte (0)
;     offset(n) = data byte (n-2)
;
; Subsequent blocks
;     offset(n) = data byte (n)
;
; The TASS assembler and most Commodore 64-based tools generate this
; data format automatically and you can transfer their .obj/.o64 output
; file directly.  
;   
; The only time you need to do anything special is if you have 
; a raw memory image file (say you want to load a data
; table into memory). For XMODEM you'll have to 
; "insert" the start address bytes to the front of the file.
; Otherwise, XMODEM would have no idea where to start putting
; the data.
;
; The "fallback" format is Intel Hex.  As address information is included
; at the start of each line of an Intel Hex file, there is no need for a special
; "first block". As soon as the receiver sees an Intel Hex
; character ':' coming in, it aborts the XMODEM-CRC upload attempt and
; tries to accept Intel Hex instead.  This is the format used natively
; by a lot of generic tools such as TASM.
; Note there is no "fallback fallback."  Once it quits CRC and 
; thinks you're sending it Intel Hex, you either have to finish the download 
; or press CTRL-C to abort.
;
; By having support for both formats under the same "U"pload command,
; it enables seamless switching between either kind of toolchain with
; no special user intervention.  This seemed like a Good Thing (tm).
;
; Note: testing shows that no end-of-line delay is required for Intel Hex
; uploads, but in case your circumstances differ and you encounter
; error indications from a download (especially if you decided to run the
; controller under 1 Mhz), adding a 10-50 mS delay after each line is 
; harmless and will ensure no problems even at low clock speeds
;
;
; Style conventions being tried on this file for possible future adoption:
; 1. Constants known at assembly time are ALL CAPS
; 2. Variables are all lower-case, with underscores used as the word separator
; 3. Labels are PascalStyleLikeThis to distinguish from constants and variables
; 4. Old labels from external modules are left alone.  We may want
;    to adopt these conventions and retrofit old source later.
; 5. Op-codes are lower-case
; 6. Comments are free-style but ought to line up with similar adjacent comments

; zero page variables (Its ok to stomp on the monitor's zp vars)
;
;
crc		=	$38		; CRC lo byte
crch		=	$39		; CRC hi byte
ptr		=	$3a		; data pointer
ptrh		=	$3b		;   "    "
blkno		=	$3c		; block number
retry		=	$3d		; retry counter
retry2	=	$3e		; 2nd counter
bflag		=	$3f		; block flag 
reclen    	=   	$39        	; record length in bytes
chksum    	=   	crc        	; record checksum accumulator
start_lo  	=   	$3b
start_hi  	=   	$3c
rectype   	=   	$3d
dlfail    	=   	$3e     	; flag for upload failure
temp      	=   	$3f     	; save hex value
strptr      =     $40
strptrh	=     $41		; temporary string pointer (not preserved across calls)

;
;  tables and constants
;
crclo    	=	$7a00      	; Two 256-byte tables for quick lookup
crchi    	= 	$7b00      	; (should be page-aligned for speed)
Rbuff		=	$0300      	; temp 128 byte receive buffer 
					; (uses the Monitor's input buffer)
SOH		=	$01		; start block
EOT		=	$04		; end of text marker
ACK		=	$06		; good block acknowleged
NAK		=	$15		; bad block acknowleged
CAN		=	$18		; cancel (not standard, not supported)
CR		=	13
LF		=	10
ESC         =     27          ; ESC to exit
                                        ;
;		*= $f700		; lo CRC lookup table
;crclo
; .byte $00,$21,$42,$63,$84,$A5,$C6,$E7,$08,$29,$4A,$6B,$8C,$AD,$CE,$EF
; .byte $31,$10,$73,$52,$B5,$94,$F7,$D6,$39,$18,$7B,$5A,$BD,$9C,$FF,$DE
; .byte $62,$43,$20,$01,$E6,$C7,$A4,$85,$6A,$4B,$28,$09,$EE,$CF,$AC,$8D
; .byte $53,$72,$11,$30,$D7,$F6,$95,$B4,$5B,$7A,$19,$38,$DF,$FE,$9D,$BC
; .byte $C4,$E5,$86,$A7,$40,$61,$02,$23,$CC,$ED,$8E,$AF,$48,$69,$0A,$2B
; .byte $F5,$D4,$B7,$96,$71,$50,$33,$12,$FD,$DC,$BF,$9E,$79,$58,$3B,$1A
; .byte $A6,$87,$E4,$C5,$22,$03,$60,$41,$AE,$8F,$EC,$CD,$2A,$0B,$68,$49
; .byte $97,$B6,$D5,$F4,$13,$32,$51,$70,$9F,$BE,$DD,$FC,$1B,$3A,$59,$78
; .byte $88,$A9,$CA,$EB,$0C,$2D,$4E,$6F,$80,$A1,$C2,$E3,$04,$25,$46,$67
; .byte $B9,$98,$FB,$DA,$3D,$1C,$7F,$5E,$B1,$90,$F3,$D2,$35,$14,$77,$56
; .byte $EA,$CB,$A8,$89,$6E,$4F,$2C,$0D,$E2,$C3,$A0,$81,$66,$47,$24,$05
; .byte $DB,$FA,$99,$B8,$5F,$7E,$1D,$3C,$D3,$F2,$91,$B0,$57,$76,$15,$34
; .byte $4C,$6D,$0E,$2F,$C8,$E9,$8A,$AB,$44,$65,$06,$27,$C0,$E1,$82,$A3
; .byte $7D,$5C,$3F,$1E,$F9,$D8,$BB,$9A,$75,$54,$37,$16,$F1,$D0,$B3,$92
; .byte $2E,$0F,$6C,$4D,$AA,$8B,$E8,$C9,$26,$07,$64,$45,$A2,$83,$E0,$C1
; .byte $1F,$3E,$5D,$7C,$9B,$BA,$D9,$F8,$17,$36,$55,$74,$93,$B2,$D1,$F0 
;
;		*= $f800		; hi CRC lookup table
;crchi
; .byte $00,$10,$20,$30,$40,$50,$60,$70,$81,$91,$A1,$B1,$C1,$D1,$E1,$F1
; .byte $12,$02,$32,$22,$52,$42,$72,$62,$93,$83,$B3,$A3,$D3,$C3,$F3,$E3
; .byte $24,$34,$04,$14,$64,$74,$44,$54,$A5,$B5,$85,$95,$E5,$F5,$C5,$D5
; .byte $36,$26,$16,$06,$76,$66,$56,$46,$B7,$A7,$97,$87,$F7,$E7,$D7,$C7
; .byte $48,$58,$68,$78,$08,$18,$28,$38,$C9,$D9,$E9,$F9,$89,$99,$A9,$B9
; .byte $5A,$4A,$7A,$6A,$1A,$0A,$3A,$2A,$DB,$CB,$FB,$EB,$9B,$8B,$BB,$AB
; .byte $6C,$7C,$4C,$5C,$2C,$3C,$0C,$1C,$ED,$FD,$CD,$DD,$AD,$BD,$8D,$9D
; .byte $7E,$6E,$5E,$4E,$3E,$2E,$1E,$0E,$FF,$EF,$DF,$CF,$BF,$AF,$9F,$8F
; .byte $91,$81,$B1,$A1,$D1,$C1,$F1,$E1,$10,$00,$30,$20,$50,$40,$70,$60
; .byte $83,$93,$A3,$B3,$C3,$D3,$E3,$F3,$02,$12,$22,$32,$42,$52,$62,$72
; .byte $B5,$A5,$95,$85,$F5,$E5,$D5,$C5,$34,$24,$14,$04,$74,$64,$54,$44
; .byte $A7,$B7,$87,$97,$E7,$F7,$C7,$D7,$26,$36,$06,$16,$66,$76,$46,$56
; .byte $D9,$C9,$F9,$E9,$99,$89,$B9,$A9,$58,$48,$78,$68,$18,$08,$38,$28
; .byte $CB,$DB,$EB,$FB,$8B,$9B,$AB,$BB,$4A,$5A,$6A,$7A,$0A,$1A,$2A,$3A
; .byte $FD,$ED,$DD,$CD,$BD,$AD,$9D,$8D,$7C,$6C,$5C,$4C,$3C,$2C,$1C,$0C
; .byte $EF,$FF,$CF,$DF,$AF,$BF,$8F,$9F,$6E,$7E,$4E,$5E,$2E,$3E,$0E,$1E 
;
;
; Xmodem/CRC upload routine
; By Daryl Rictor, July 31, 2002
;
;
; v0.3  tested good minus CRC
; v0.4  CRC fixed!!! init to $0000 rather than $FFFF as stated   
; v0.5  added CRC tables vs. generation at run time
; v 1.0 recode for use with SBC2
; v 1.1 added block 1 masking (block 257 would be corrupted)
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

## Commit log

2018-10-27 Issue 4
    [bravo-v3.brd, bravo-v3.sch, bravo-v4.brd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]
2018-10-27 Issue 4 gerber files
